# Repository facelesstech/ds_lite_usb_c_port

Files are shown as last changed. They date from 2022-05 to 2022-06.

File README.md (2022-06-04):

# DS lite USB C port

Items you will need.
  * [6 pin USB C Port](https://www.aliexpress.com/item/32966491026.html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)
  * [5.1k 0603 SMD resistors x2](https://www.aliexpress.com/item/1005001436923851.html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)

# Assembly of the USB C charge port PCB

Remove the mouse bits from the PCB with a file. Place the USB C port into place and secure the anchor legs with some solder. Flip the PCB over and solder all 6 of the USB C port pins. Flux and a fine soldering iron tip is advised. Next solder in place the 5.1k 0603 smd resistors, Add solder to one side of the pads and with tweezers place the resistor and heat the solder to secure, If you are happy with the placement add solder to the other pad.

# Installing USB C charge port

Remove your old charge port, This can be done with a hot air work station.

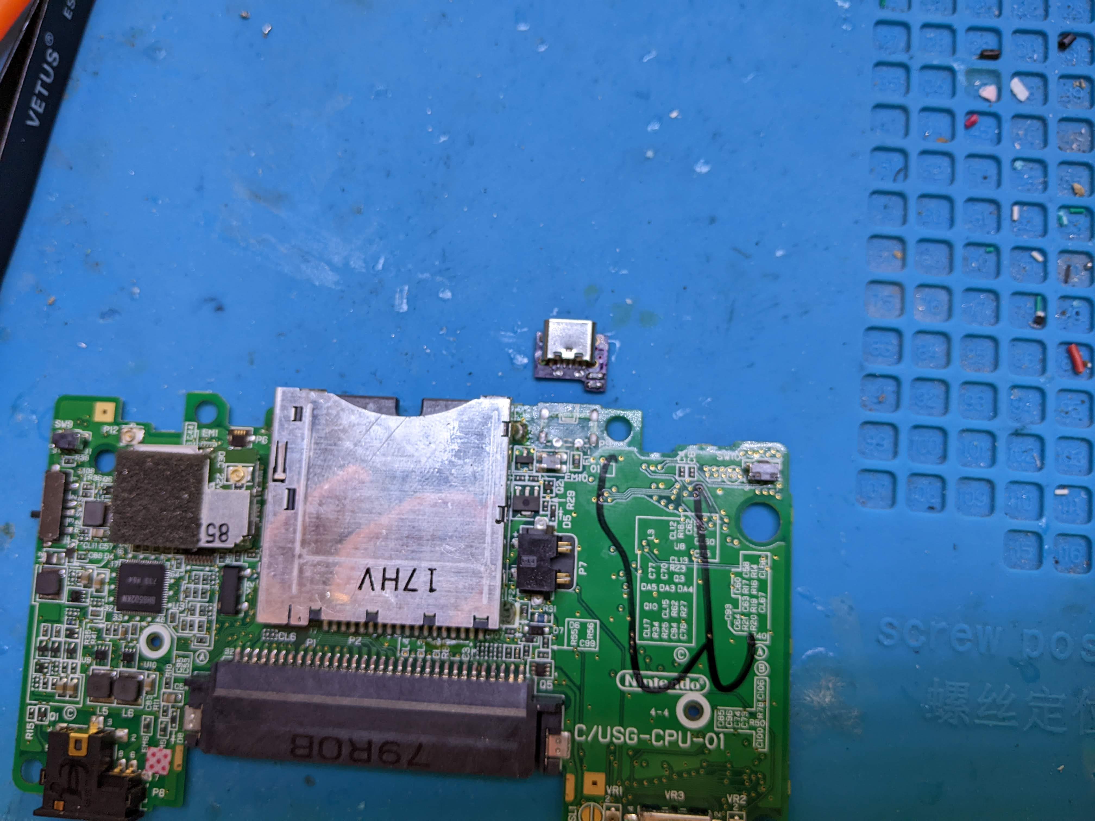
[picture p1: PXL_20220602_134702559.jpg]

Line the two bottom holes in the PCB up with the two holes in the ds lites charge port, Making sure that the USB C PCB doesn't stick out over the edge of the DS Lite PCB. Solder then into place. Test to see if your DS Lite charges with the new port, If so then solder the other 4 anchor points from the old charge port to secure the new PCB.



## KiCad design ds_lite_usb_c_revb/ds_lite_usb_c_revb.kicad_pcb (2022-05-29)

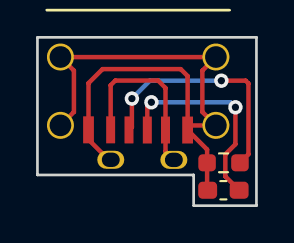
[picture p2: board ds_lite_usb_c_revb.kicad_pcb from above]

Board: 2 copper layers, 12.2 x 9.4 mm, 4 parts (0 on the bottom side), 4 nets.

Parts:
R1: R; R_0603_1608Metric_Pad1.05x0.95mm_HandSolder
R2: R; R_0603_1608Metric_Pad0.98x0.95mm_HandSolder
U1: usb_c_6pin; USB_C_6PIN_custom
U2: battery_custom; ds_lite_charger_pins

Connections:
unnamed: R1.1, U1.4
unnamed: R1.2, R2.2, U1.1, U2.1
unnamed: R2.1, U1.3
unnamed: U1.2, U2.2
